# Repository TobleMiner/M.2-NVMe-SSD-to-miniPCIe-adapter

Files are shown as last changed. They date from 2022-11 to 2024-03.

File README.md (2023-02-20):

M.2 Key M to miniPCIe adapter
=============================

Especially slightly aged PCIe-enabled equipment intended for computer
networking applications often feature miniPCIe slots. Adding storage
capability to this type of device can be difficult. Even if one or more
of the mini PCIe slots are SATA-enabled availability of fitting mSATA SSDs
is continually becoming worse as mSATA SSDs have started to drift into
obscurity.  
This project is aimed at providing an option for fast, high reliability
NVMe-based storage in devices that do not have any M.2 Key M but only
miniPCIe slots.  
One example of such a device is the PCengines APU2, an AMD64 network
platform with up to two PCIe-enabled miniPCIe slots.

## Compatible SSDs

A bit of care has to be taken when selecting a SSD compatible with the
adapter. It only supports 2230 and 2242 M.2 PCIe SSDs. The more common
2280 size is not supported due to size constraints.  
Depending on the device the adapter is to be used in even 2242 M.2 SSDs
might not fit.  
I've had good sucess using Samsung PM991 NVMe SSDs.

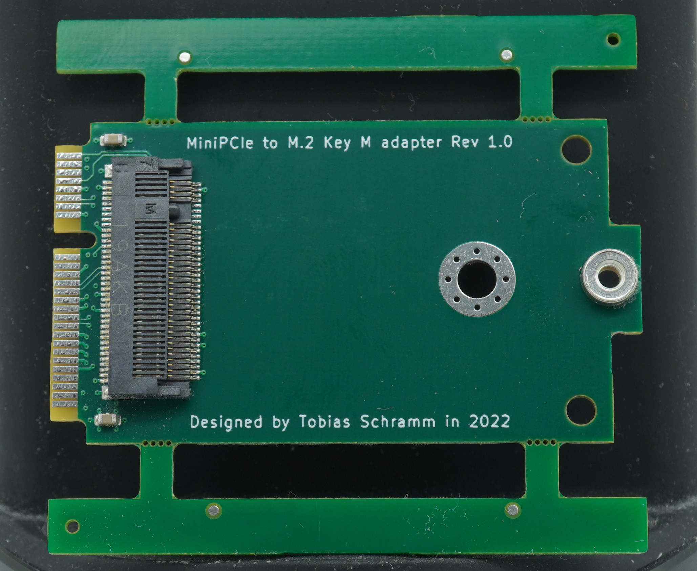
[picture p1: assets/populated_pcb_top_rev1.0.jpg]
Photo of the adapter PCB


# Ordering

The fabrication files inside `fab` are JLCPCB-ready. The board must be
ordered with a 1.0mm board thickness to fit the miniPCIe slot.  
Additionally I'd highly recommend selecting the "controlled impedance"
option with 7628 stackup. The PCIe interface has been routed with that
stackup in mind.

## Limitations

Currently this board does neither use gold plating nor edge beveling on
the miniPCIe contact fingers. While good for cost reduction in small
production runs this is not ideal.  
When ordering through JLCPCB at the time of writing the PCB would have
to be adjusted (minimum size 70x70mm) to be able to get beveled edges
and gold plating.

# Use

The following picture shows two of the adapters installed in an APU2
with Samsung PM991 NVMe SSDs.

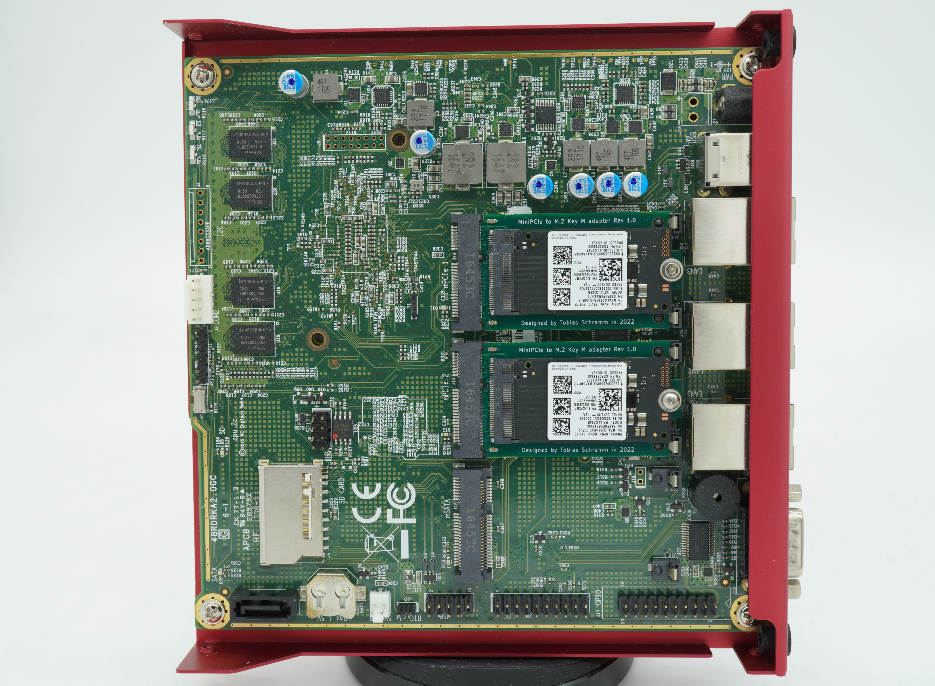
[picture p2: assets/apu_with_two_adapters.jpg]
Photo of two adapters installed in a PCengines APU


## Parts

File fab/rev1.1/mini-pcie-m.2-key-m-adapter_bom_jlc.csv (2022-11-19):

Comment | Designator | Footprint | LCSC Part #
22uF | C1,C2 | C_0603_1608Metric | C59461
MountingHole_Pad | H1 | MountingHole_3.6mm_small | C2928188
Bus_M.2_Socket_M | J2 | MDTXXXXXX001 | C2832351

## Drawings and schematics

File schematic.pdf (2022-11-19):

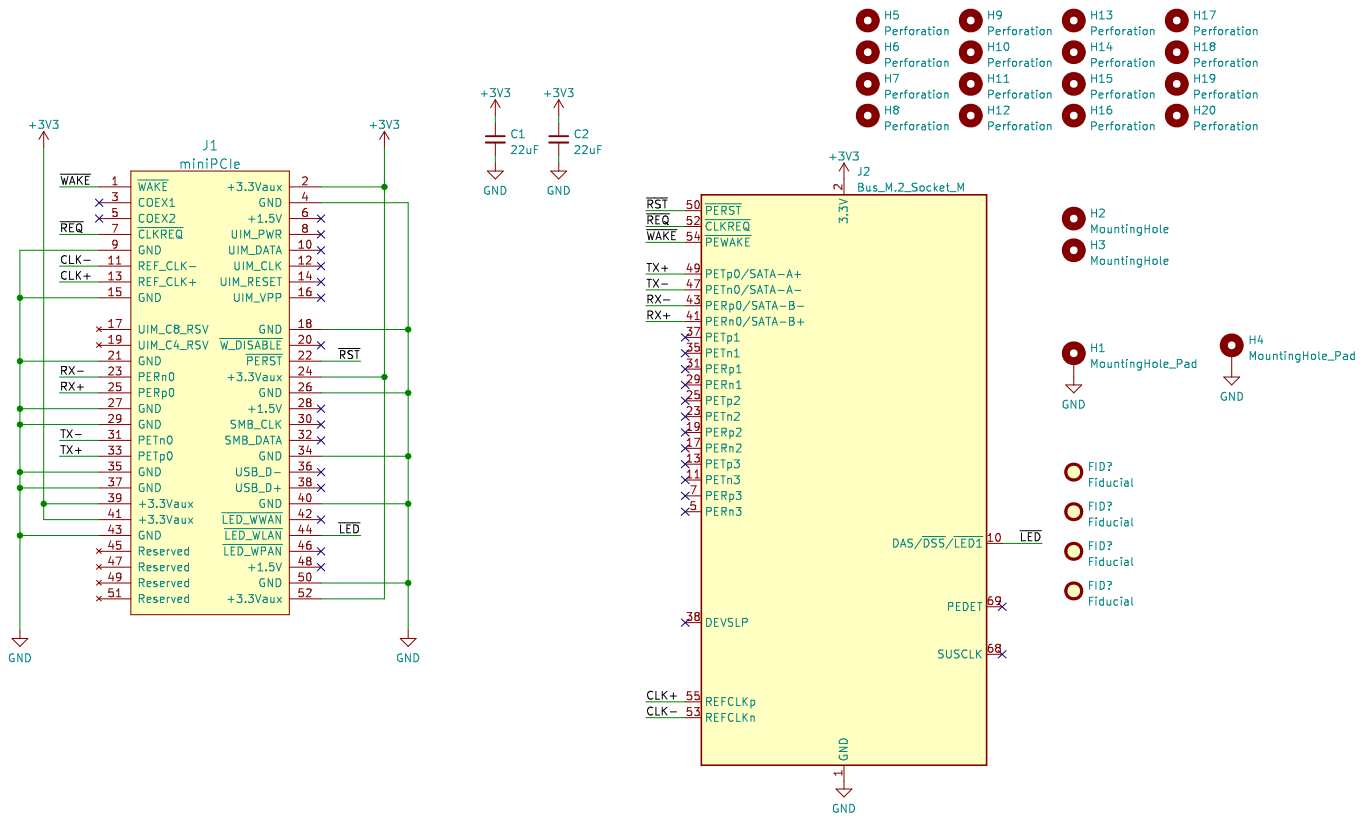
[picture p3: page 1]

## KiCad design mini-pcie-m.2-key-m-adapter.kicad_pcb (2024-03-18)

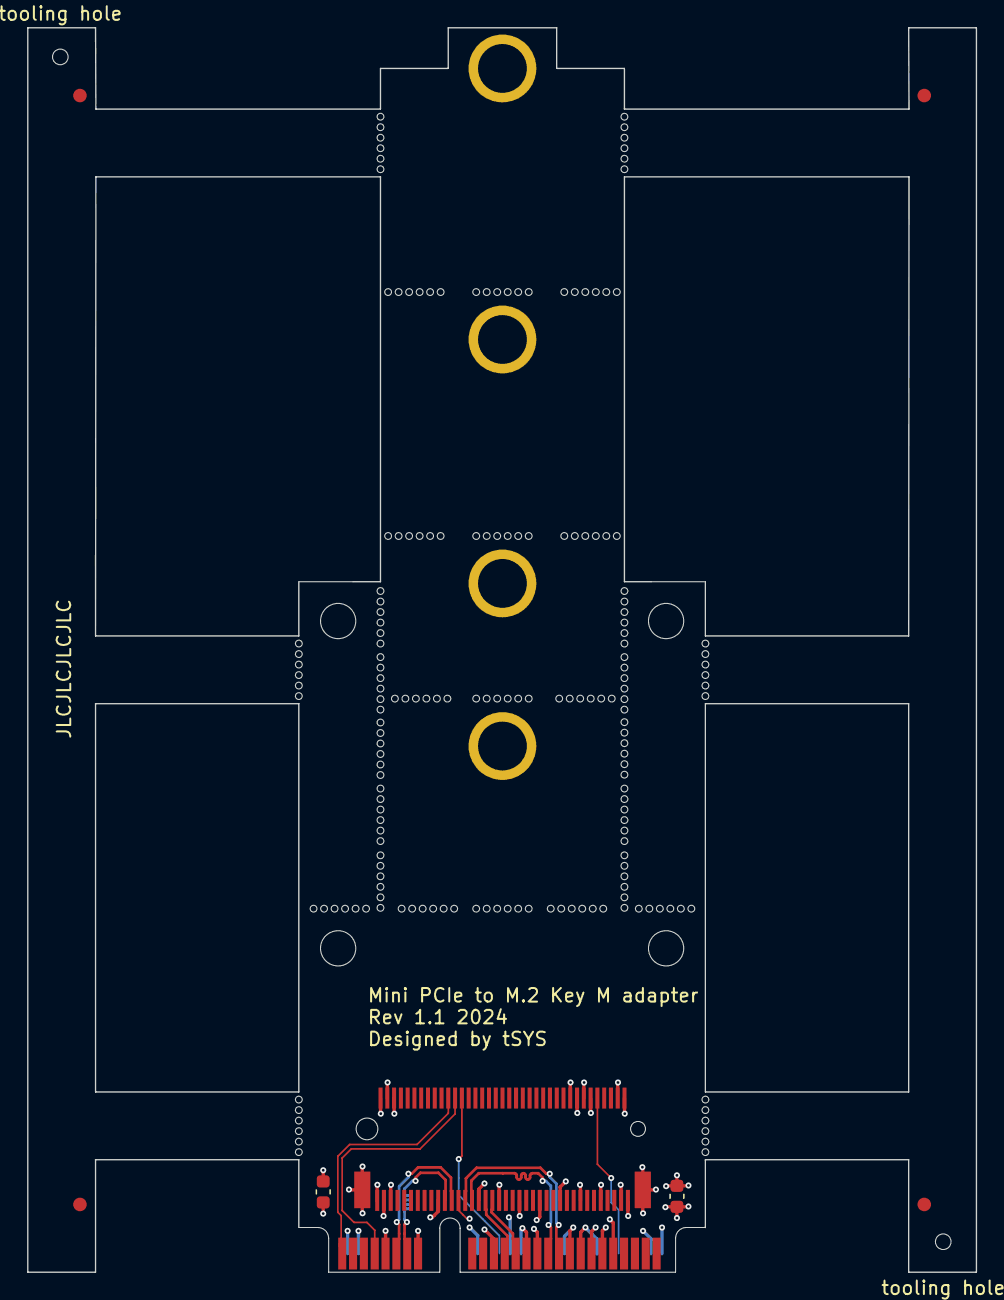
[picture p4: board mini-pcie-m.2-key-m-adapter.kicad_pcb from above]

Board: 4 copper layers, 70.0 x 91.8 mm, 6 parts (0 on the bottom side), 12 nets.

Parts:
C1, C2: 22uF; C_0603_1608Metric
H2, H3: MountingHole; ToolingHole_JLCSMT
J1: miniPCIe; mini-PCIe_F1_Full
J2: Bus_M.2_Socket_M; MDTXXXXXX001

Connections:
+3V3: C1.1, C2.1, J1.2 (+3.3Vaux), J1.24 (+3.3Vaux), J1.39 (+3.3Vaux), J1.41 (+3.3Vaux), J1.52 (+3.3Vaux), J2.2 (3.3V), J2.4 (3.3V), J2.12 (3.3V), J2.14 (3.3V), J2.16 (3.3V), J2.18 (3.3V), J2.70 (3.3V), J2.72 (3.3V), J2.74 (3.3V)
/CLK+: J1.13 (REF_CLK+), J2.55 (REFCLKp)
/CLK-: J1.11 (REF_CLK-), J2.53 (REFCLKn)
/RX+: J1.25 (PERp0), J2.41 (PERn0/SATA-B+)
/RX-: J1.23 (PERn0), J2.43 (PERp0/SATA-B-)
/TX+: J1.33 (PETp0), J2.49 (PETp0/SATA-A+)
/TX-: J1.31 (PETn0), J2.47 (PETn0/SATA-A-)
/~LED: J1.44 (~LED_WLAN), J2.10 (DAS/~DSS/~LED1)
/~REQ: J1.7 (~CLKREQ), J2.52 (~CLKREQ)
/~RST: J1.22 (~PERST), J2.50 (~PERST)
/~WAKE: J1.1 (~WAKE), J2.54 (~PEWAKE)
GND: C1.2, C2.2, J1.4 (GND), J1.9 (GND), J1.15 (GND), J1.18 (GND), J1.21 (GND), J1.26 (GND), J1.27 (GND), J1.29 (GND), J1.34 (GND), J1.35 (GND), J1.37 (GND), J1.40 (GND), J1.43 (GND), J1.50 (GND), J2.1 (GND), J2.3 (GND), J2.9 (GND), J2.15 (GND), J2.21 (GND), J2.27 (GND), J2.33 (GND), J2.39 (GND), J2.45 (GND), J2.51 (GND), J2.57 (GND), J2.71 (GND), J2.73 (GND), J2.75 (GND), J2.MP

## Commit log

2022-11-19 Add M.2 connector 3D model
    [mini-pcie-m.2-key-m-adapter.kicad_pcb]
2022-11-19 Add fabrication files
    [mini-pcie-m.2-key-m-adapter_bom_jlc.csv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]
2022-11-19 Add schematic pdf export
2023-02-20 Update README.md
    Changed board thickness on line 30 from 1.2mm to 1.0mm - I ordered a batch with 1.2mm and found they do not fit, and a quick Google search indicates the miniPCIe spec is 1.0mm.
2024-03-18 lib: ToolingHole: update to latest version
    New version has fiducials and mousebites for JLC standard assembly
2024-03-18 lib: kicad-mini-pci-e: add half-size mounting holes to mini PCIe card
2024-03-18 Add 60mm and 80mm M.2 mounting options
    [mini-pcie-m.2-key-m-adapter-B_Cu.gbl, mini-pcie-m.2-key-m-adapter-B_Mask.gbs, mini-pcie-m.2-key-m-adapter-B_Paste.gbp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]
